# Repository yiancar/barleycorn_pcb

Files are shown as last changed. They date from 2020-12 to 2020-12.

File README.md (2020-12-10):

Barleycorn
================

barleycorn

This ANSI/ISO 1800 F-row less keyboard kit is made using ONLY through hole components and inspired by the [Plaid](https://github.com/hsgw/plaid).

Atmega328p with VUSB on [QMK firmware](https://github.com/qmk/qmk_firmware).

To alter the pcb use KiCAD V5.0 or newer as it already contains most of the libraries. The additional libraries are provided.

License
===========

This project is licensed under the [Creative Commons Attribution-NonCommercial 4.0 International License](https://creativecommons.org/licenses/by-nc/4.0/).

If you have remixed, adapted or build upon this work and wish to remove the non-commercial clause for your own project please contact me at https://www.yiancar-designs.com. Your request is more than likely to be granted. The non-commercial part of the license is intended to avoid direct copies of the work to be sold for commercial gain by third parties.

The USB4085-GF-A footprint, symbol and 3D model are licensed under [Attribution-ShareAlike 4.0 International](https://creativecommons.org/licenses/by-sa/4.0/). Originally created by [SnapEDA](https://snapeda.com). The footprint has been modified to increase the hole size of the shield pads.



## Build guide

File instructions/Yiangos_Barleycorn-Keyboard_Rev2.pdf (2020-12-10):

# Assembly Instructions

# Barleycorn Keyboard

# Welcome to your new

Barleycorn Keyboard.

Before we start, make sure you have the following:

- Soldering Iron
- Solder
- Cutters
- Stabilizers
- Mechanical Switches (preferably PCB mount)
- Keycaps
- USB C cable

This kit is designed with only through-hole components.

Component Identification

4.7uF Electrolytic
Capacitor

75Ohm Resistors
Colours: Purple,
Green, Black Gold,
Brown

22pF Ceramic
Capacitors
Markings: 22

10k Ohm Resistor
Colours: Brown, Black,
Black, Red, Brown

100nF Ceramic
Capacitors
Markings: 104

1.5k Ohm Resistors
Colours: Brown, Green,
Black, Brown, Brown

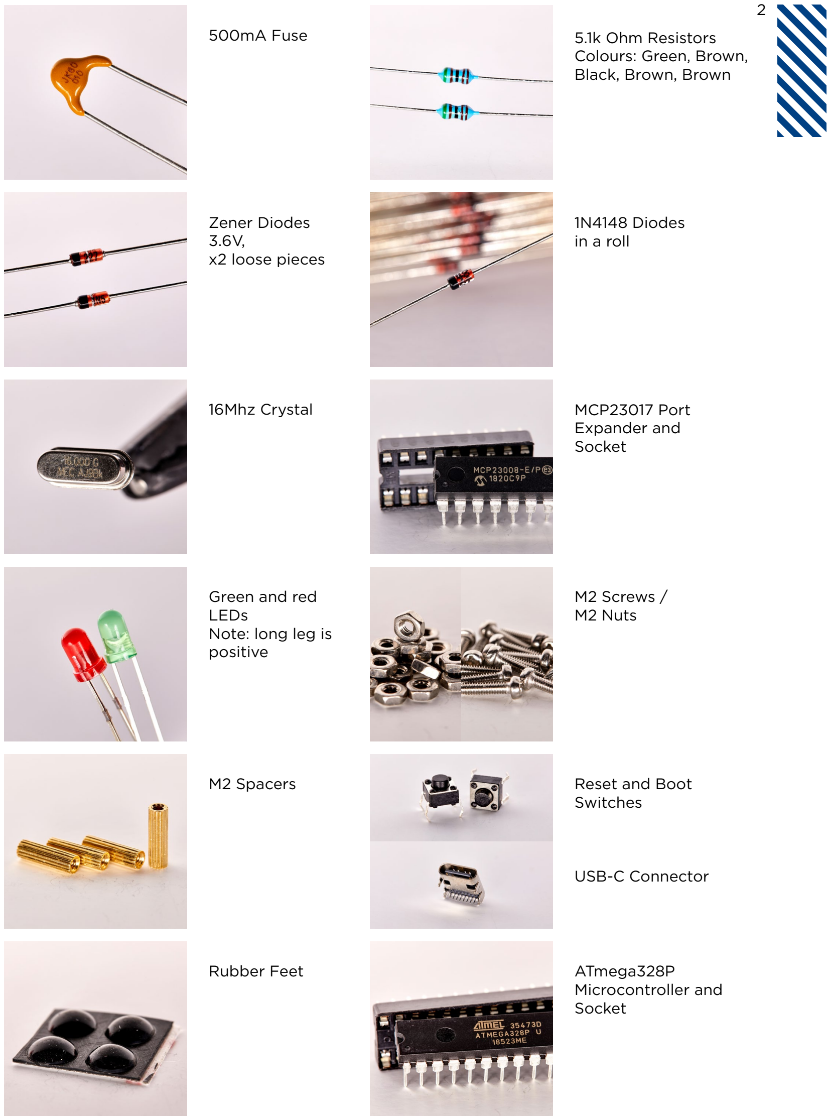
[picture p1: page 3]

500mA Fuse

1N4148 Diodes
in a roll

Zener Diodes
3.6V,
x2 loose pieces

MCP23017 Port
Expander and
Socket

16Mhz Crystal

M2 Screws /
M2 Nuts

Green and red
LEDs
Note: long leg is
positive

Reset and Boot
Switches

USB-C Connector

M2 Spacers

Rubber Feet | ATmega328P Microcontroller and Socket

5.1k Ohm Resistors
Colours: Green, Brown,
Black, Brown, Brown

# Assembly Instructions

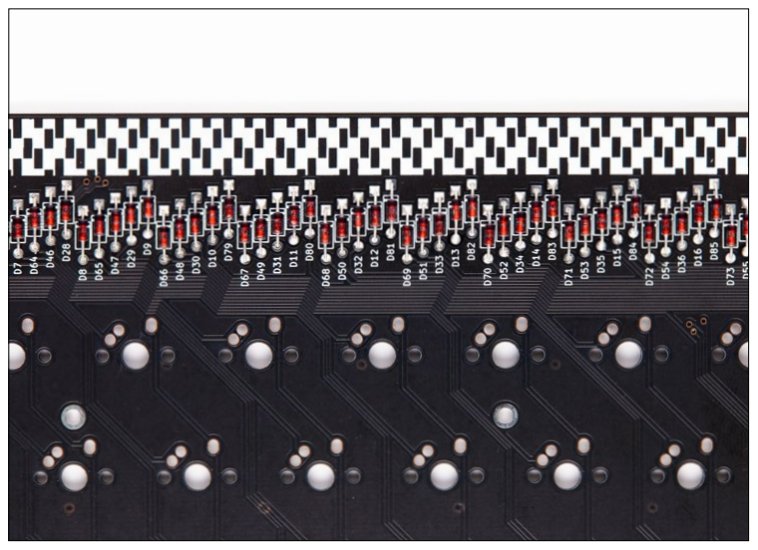
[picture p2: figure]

Step 1

Solder 1N4148 Diodes under the graphic as shown in the picture. The black line from the diodes goes to the top.

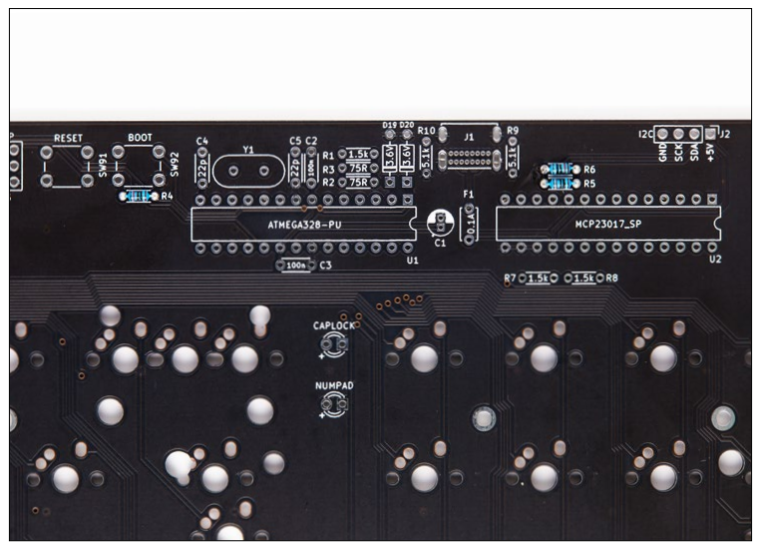
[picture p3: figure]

Step 2

Solder the x3 10k Ohm resistors; R4, R5, and R6. Those components have no specific orientation.

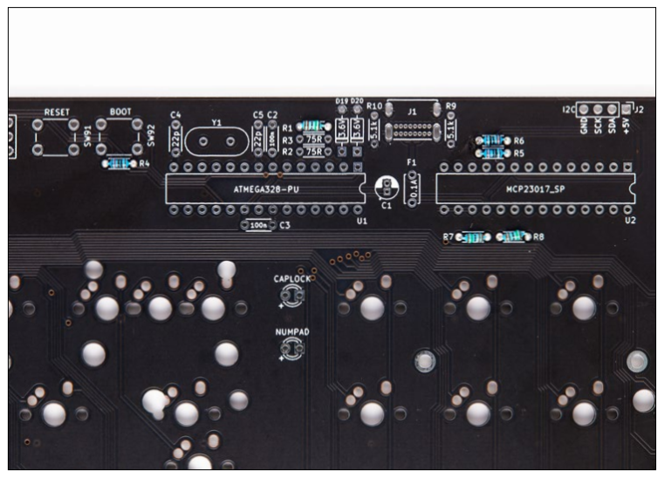
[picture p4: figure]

Step 3

Solder the x3 1.5k Ohm resistors; R1, R7, and R8. Those components have no specific orientation.

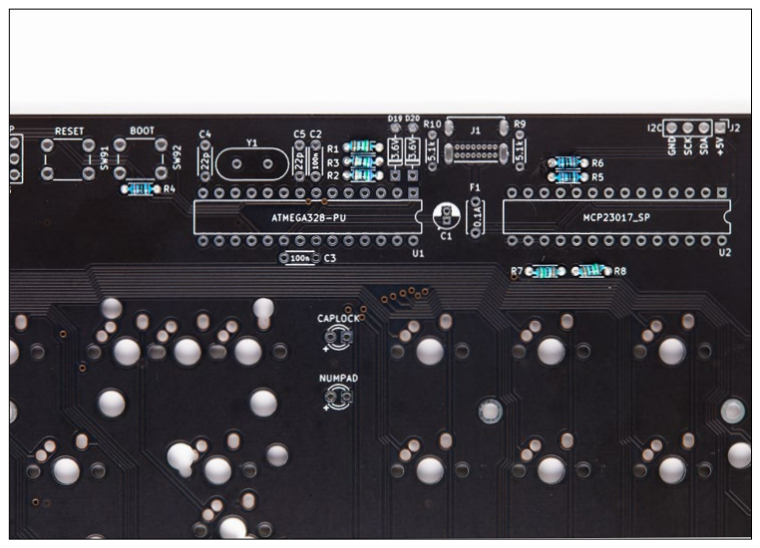
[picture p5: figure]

Step 4

Solder the x2 75 Ohm resistors; R2 and R3. Those components have no specific orientation.

# Assembly Instructions

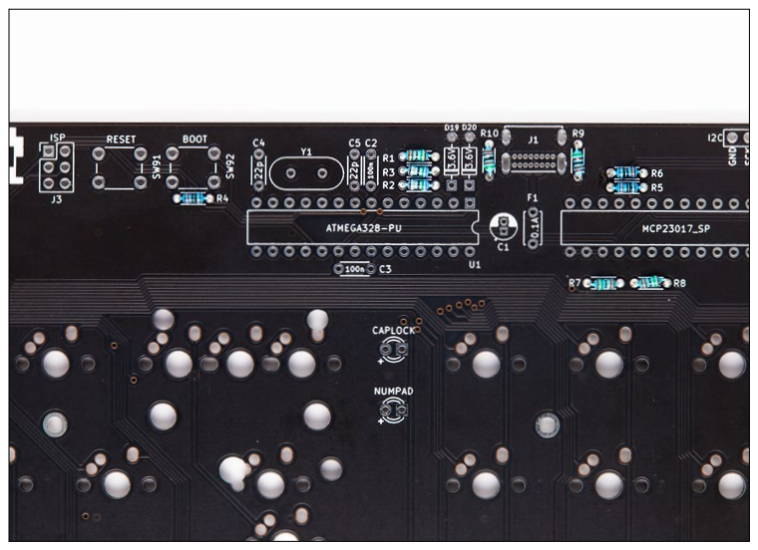
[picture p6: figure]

Step 5

Solder the x2 5.1k Ohm resistors; R9 and R10. These components have no specific orientation.

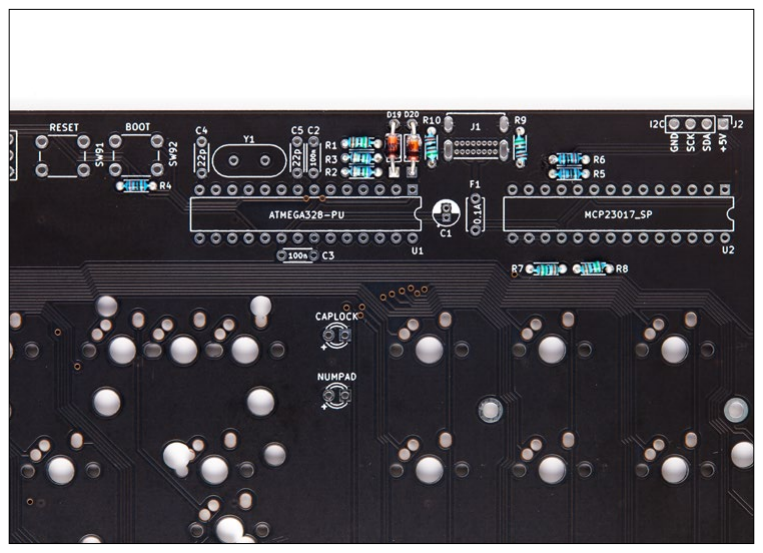
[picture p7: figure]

Step 6

Solder the x2 Zener diodes; D19 and D20. The black line is at the bottom.

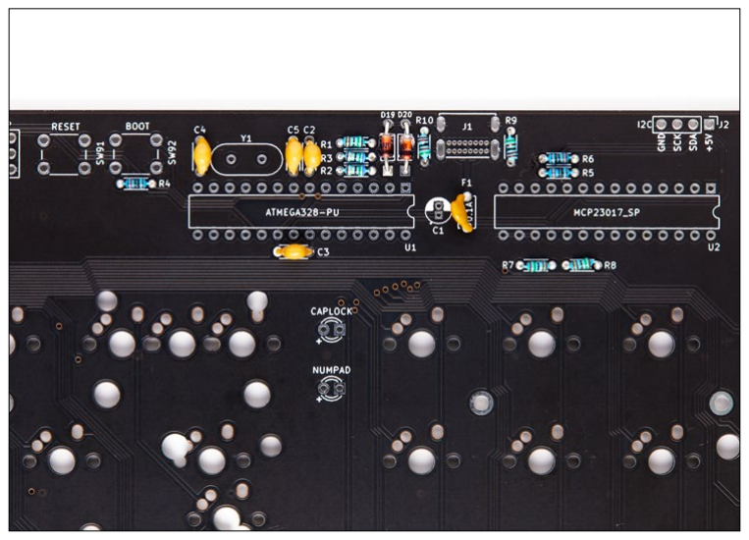
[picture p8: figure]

Step 7

Solder the x2 22pF capacitors; C4 and C5.

Note: Do not over-pull the legs through the PCB. These capacitors are very fragile and can crack. These components have no specific orientation.

Solder the x2 100nF capacitors; C2 and C3. These components have no specific orientation.

Solder the fuse, F1. This component has no specific orientation.

# Assembly Instructions

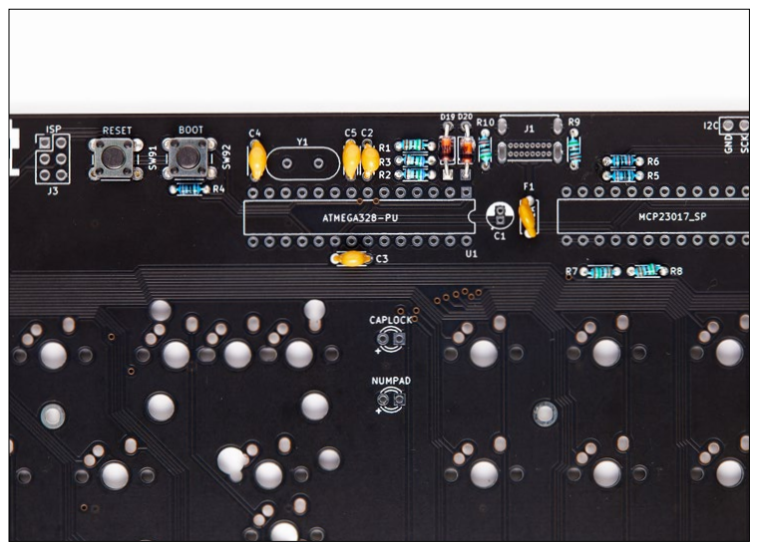
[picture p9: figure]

Step 8

Solder the x2 switches; SW91 and SW92. These components have no specific orientation.

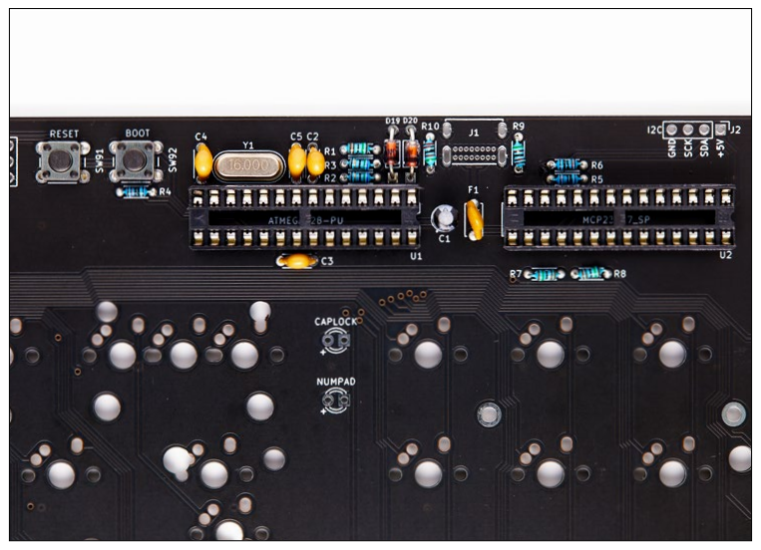
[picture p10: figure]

Step 9

Solder the electrolytic capacitor, C1. Negative (-) goes at the top. Solder the crystal at Y1, this component does not have any specific orientation.

Solder the x2 chip sockets. The small one goes to the U2 and the big one goes to U1, as in the picture.

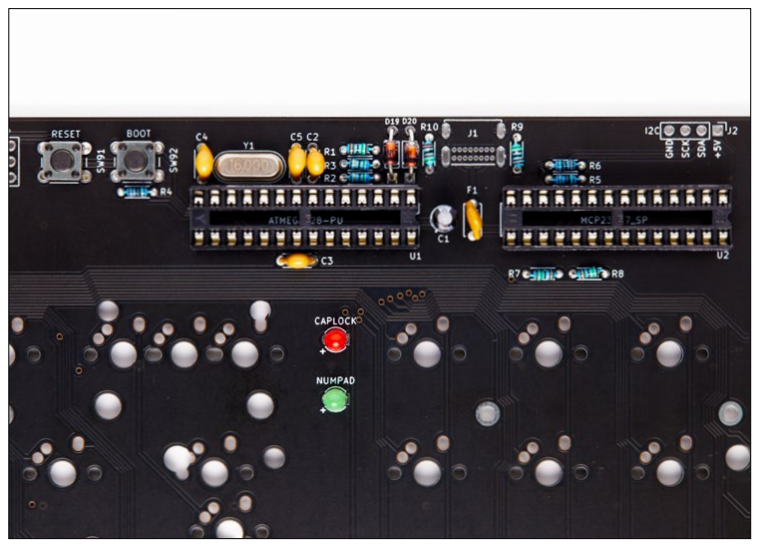
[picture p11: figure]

Step 10

Solder the LEDs as shown in the picture. The long leg is the positive.

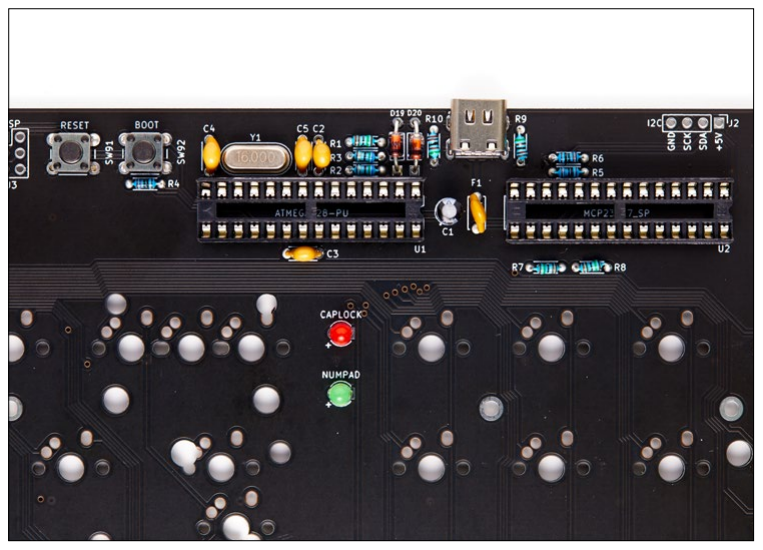
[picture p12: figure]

Step 11

Solder the USB socket. The small pins might not come through the PCB but still add plenty of solder and flux. Solder the shield pins last.

# Assembly Instructions

Step 12

Put the x2 chips in their sockets. The MCU is pre-programmed with the default ANSI keymap. Re-programming instructions are on page 9. The U1 chip’s semi-circle mark goes to the right. The U2 semi-circle mark goes to the right. Bend the legs of the chips inwards to fit in the sockets!

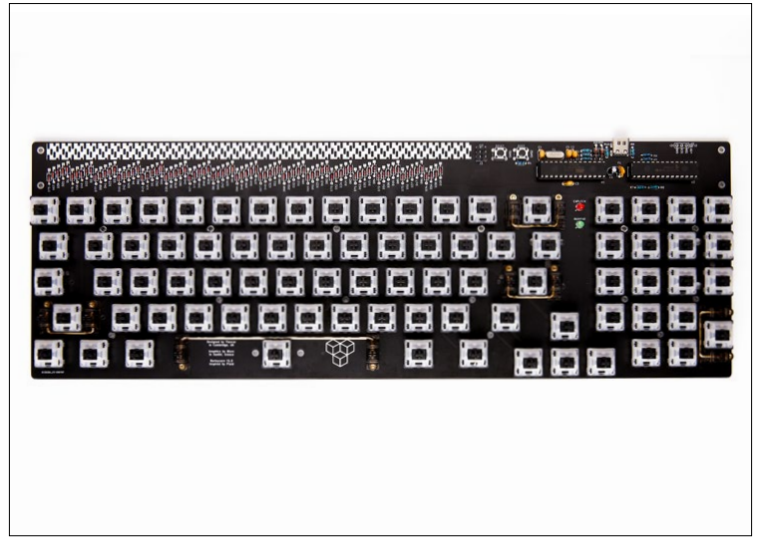
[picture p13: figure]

Step 13

Solder all the switches according to your desired layout. Add the stabilizers.

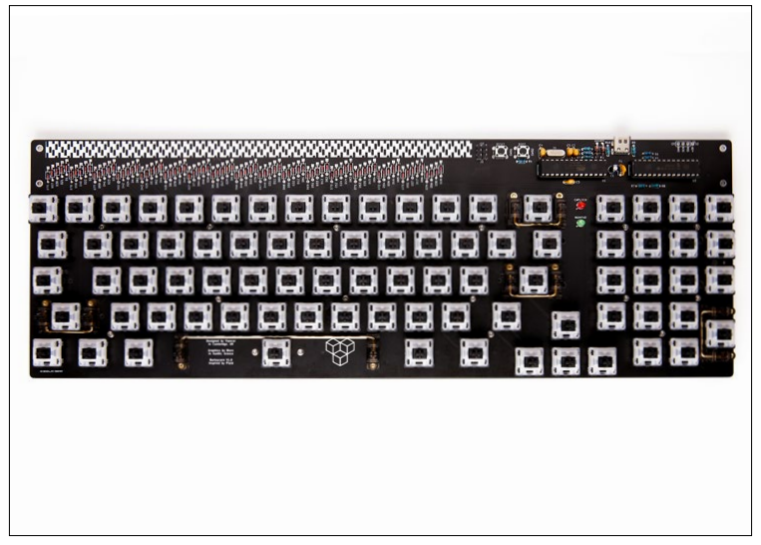
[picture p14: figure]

Step 14

Screw the x16 M2 screws as shown in the picture. Don’t add screws at the 4 top holes for the plexyglass. The screws are inserted from the top of the PCB.

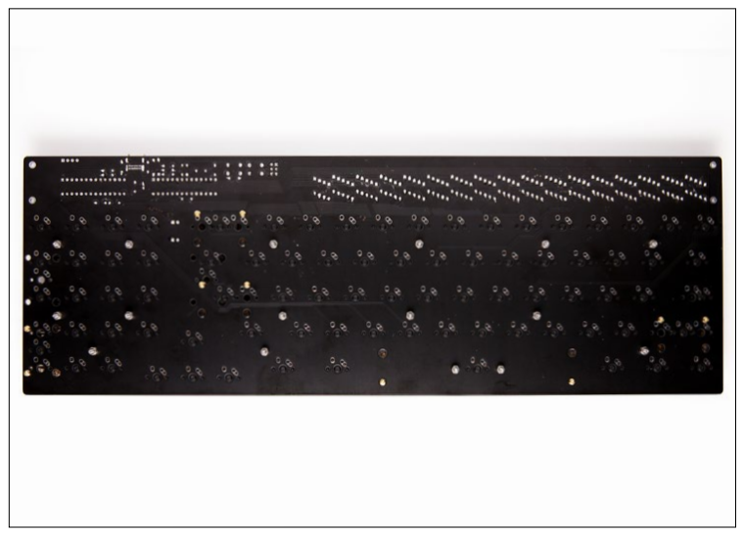
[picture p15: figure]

Step 15

Screw x2 M2 nuts on each of the 16 screws from the bottom.

# Assembly Instructions

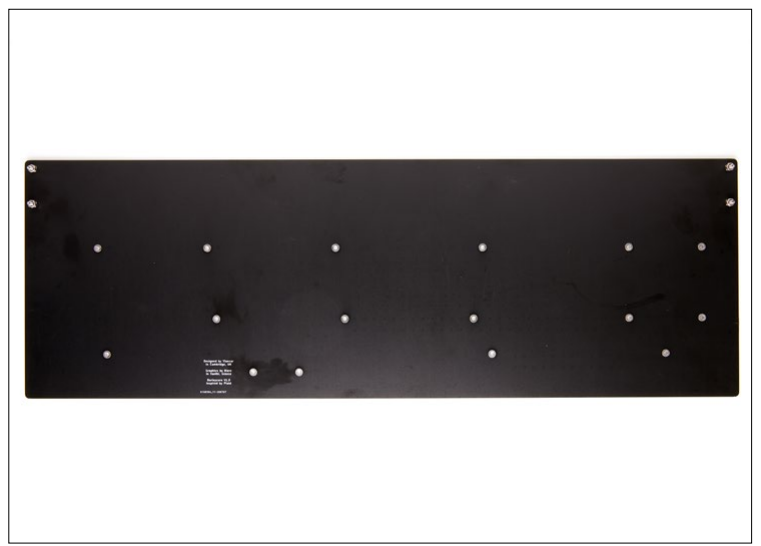
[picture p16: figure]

Step 16

Put the x4 M2 screws from the bottom of the bottom PCB. These screws are for the plexiglass.

Add x2 M2 nuts for each screw from the top of the bottom PCB.

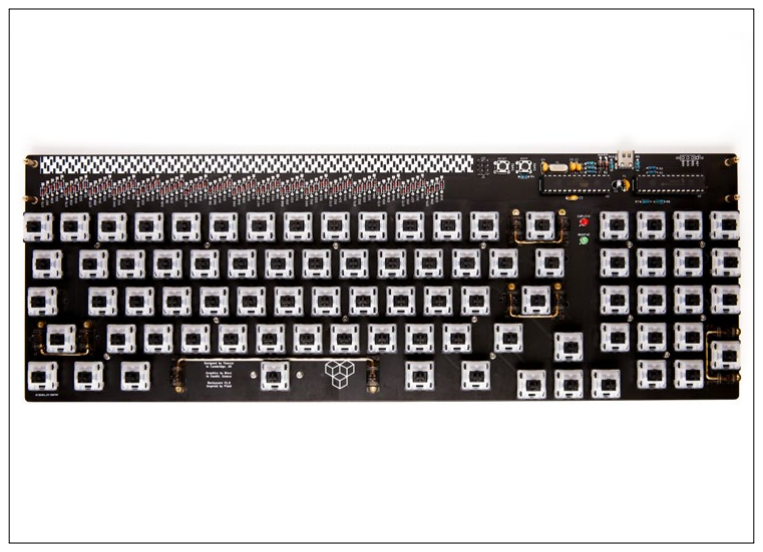
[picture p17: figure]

Step 17

Insert the bottom PCB and the top PCB together. Secure the x4 plexiglass screws with the x4 spacers.

Step 18

Place the plexiglass on top of the spacers and secure it with x4 M2 screws.

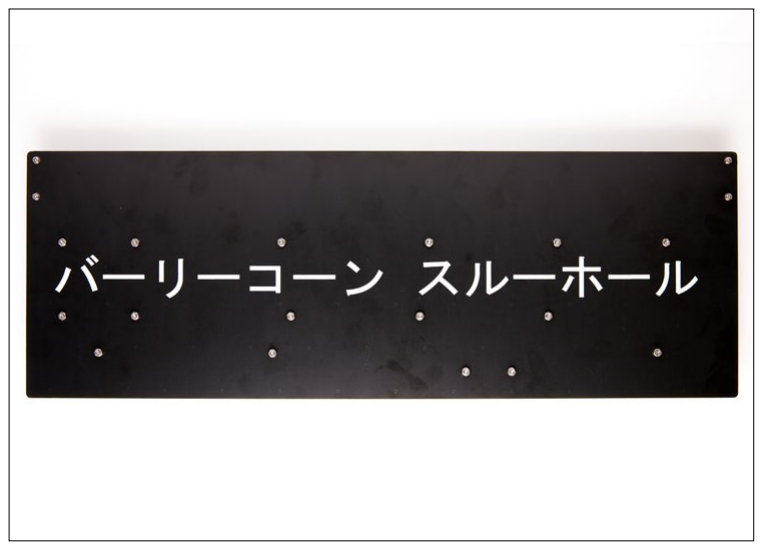
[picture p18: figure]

Step 19

Turn the keyboard upside down and secure the bottom PCB with the last x16 M2 nuts.

# Assembly Instructions

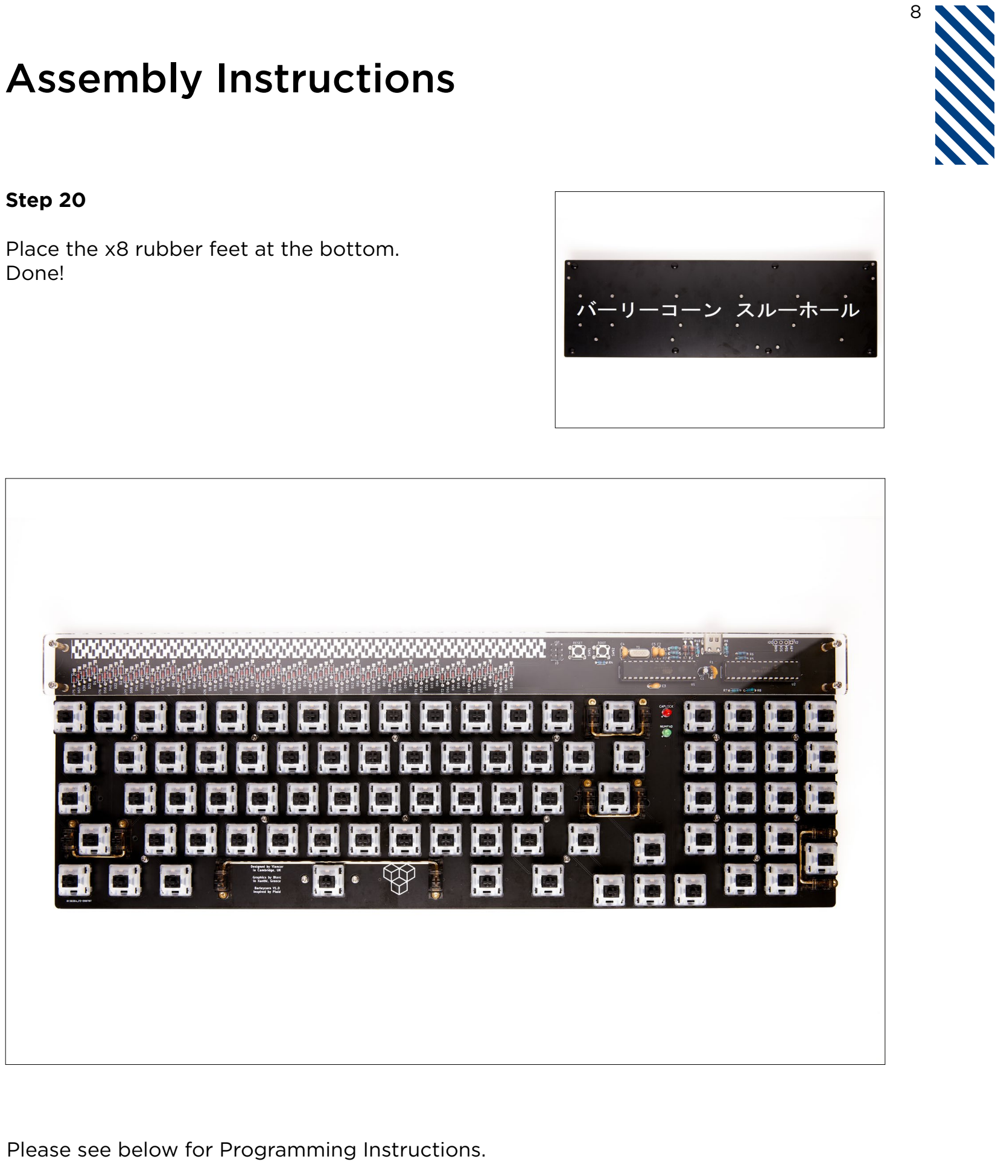
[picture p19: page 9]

Step 20

Place the x8 rubber feet at the bottom. Done!

Please see below for Programming Instructions.

# Programming Instructions Using VIA

Currently, media and mouse keycodes cannot be used using VIA.

The keyboard is shipped with VIA enabled. If you have programmed using QMK configurator and want to go back to VIA please flash the VIA keymap from our website.

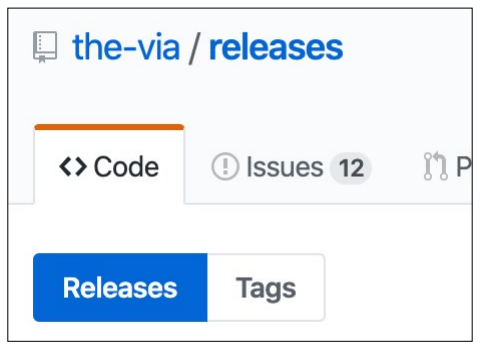
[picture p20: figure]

Step 1

Download VIA from:

https://github.com/the-via/releases/releases/latest (https://github.com/the-via/releases/releases/latest)

Step 2

With the keyboard connected, open VIA.

Step 3

To change the keymap, press on the desired key and then select the new keycode from below. The change is instantaneous.

To change layouts, use the layout tab.

# Programming Instructions Using QMK

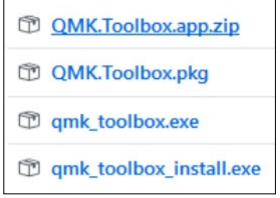
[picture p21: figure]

Step 1

Download the latest QMK Toolbox from:

https://github.com/qmk/qmk_toolbox/releases (http://github.com/qmk/qmk_toolbox/releases)

If you are using Windows download the “.exe”. If you are using MacOS download the “.pkg”.

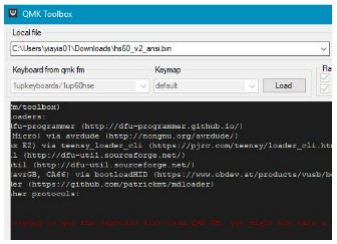
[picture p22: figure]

Step 2

Install the downloaded package.

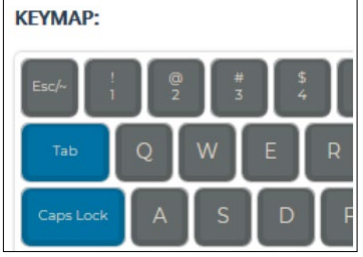
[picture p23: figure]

Step 3

Create your desired keymap from:

https://config.qmk.fm/#/barleycorn/LAYOUT_all (https://config.qmk.fm/#/barleycorn/LAYOUT_all)

Select the desired layout first.

Step 4

Press Compile button. Make sure the compilation has completed successfully.

# Programming Instructions Using QMK

Step 5

Press FIRMWARE button to download the “.hex”.

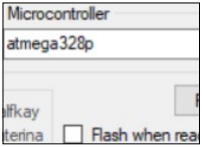
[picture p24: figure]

Step 6

In QMK toolbox press Open and select the downloaded “.hex”. Select atmega328p from the microcontroller menu.

Step 7

Press and hold the BOOT button. Press and release the RESET button. Release the BOOT button, QMK toolbox should detect USBasp.

Step 8

Press the Flash button in QMK toolbox. Once you see the Success message, press the RESET button.

Done! Enjoy your new keymap!

## yiancar-designs.com hello@yiancar-designs.com (http://yiancar-designs.com/contact-us/)

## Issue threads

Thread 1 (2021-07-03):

Missing Step in instructions

FlamingChickenG, 2021-07-03:
Missing step to solder on the 16Mhz Crystal to the board between steps 8 and 9.

yiancar, 2021-07-03:
Hello,
it says it at the text of step 9:
https://raw.githubusercontent.com/yiancar/barleycorn_pcb/main/instructions/Yiangos_Barleycorn-Keyboard_Rev2.pdf

Closed 2021-07-05.

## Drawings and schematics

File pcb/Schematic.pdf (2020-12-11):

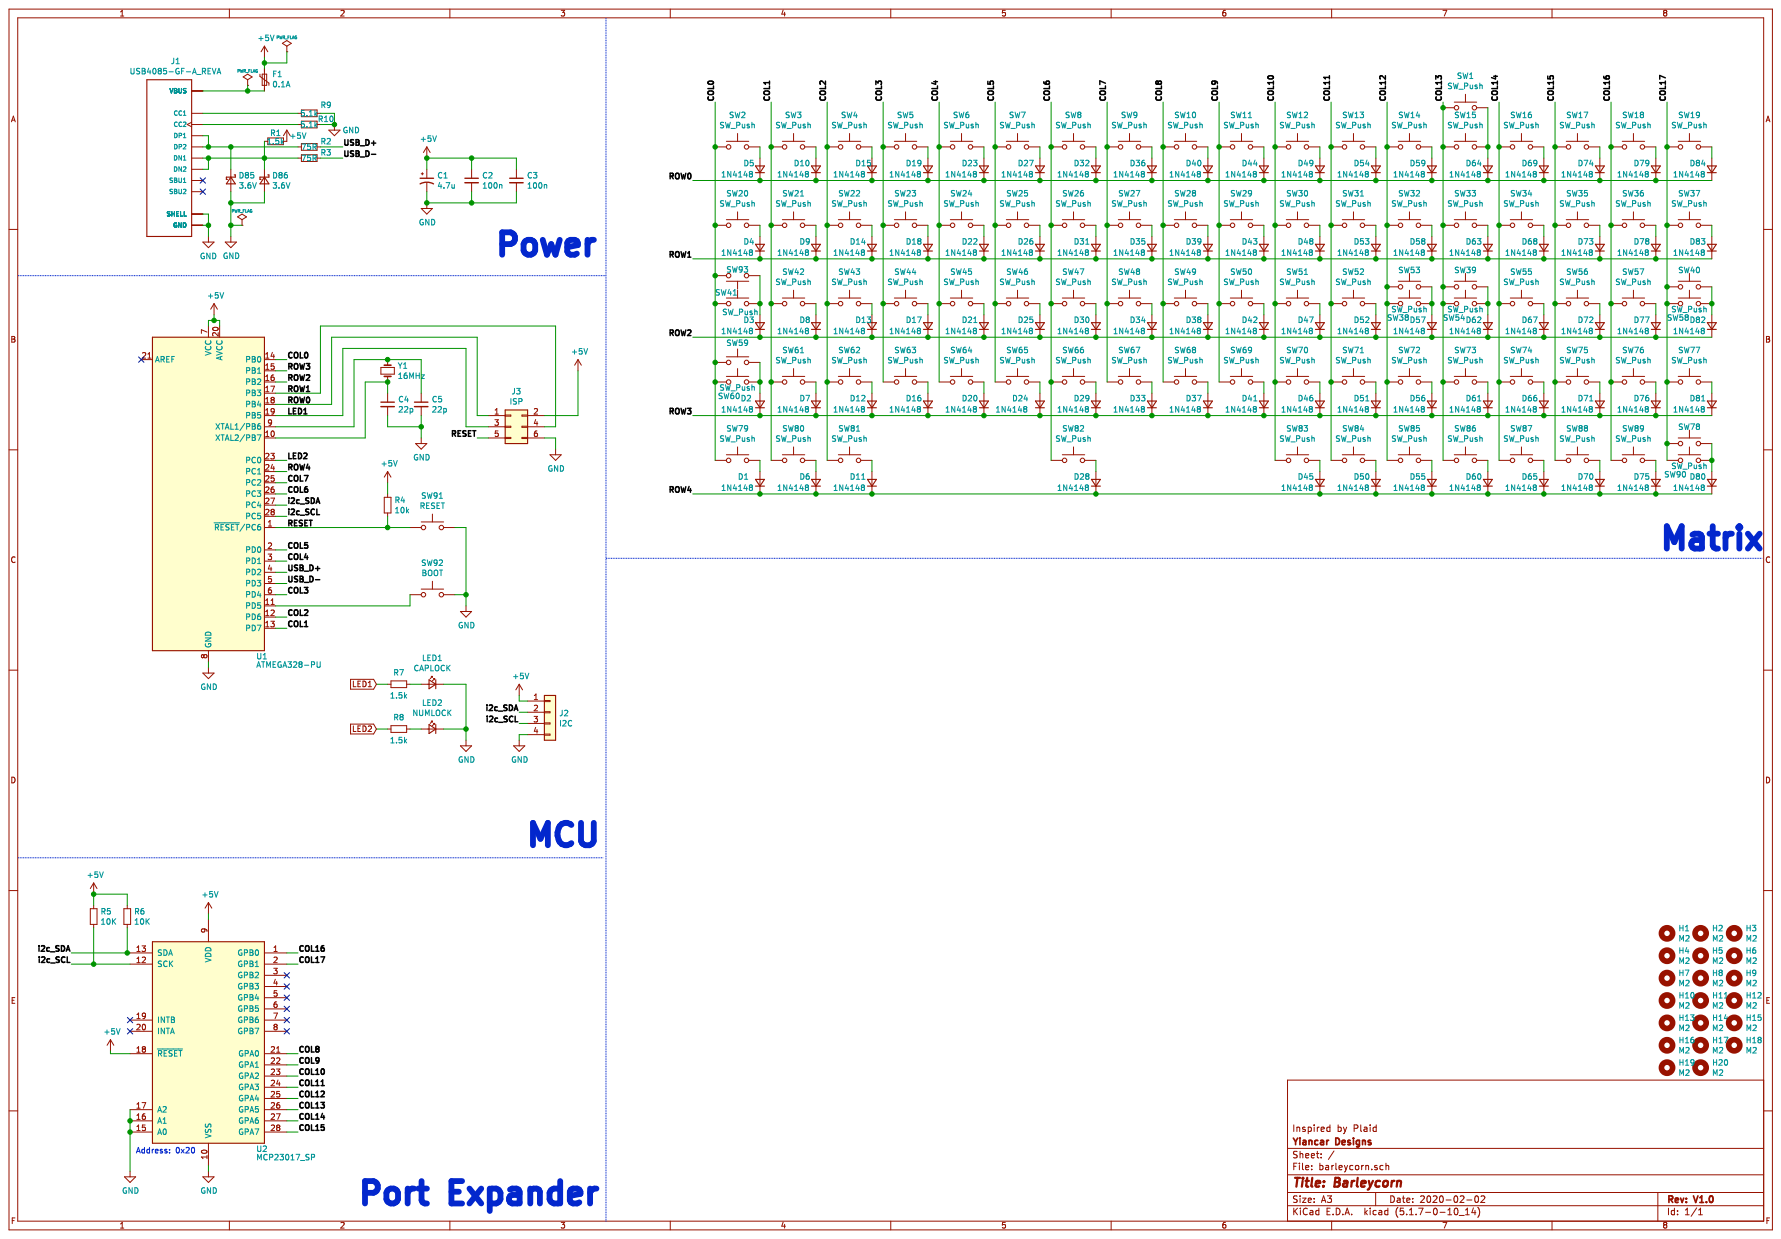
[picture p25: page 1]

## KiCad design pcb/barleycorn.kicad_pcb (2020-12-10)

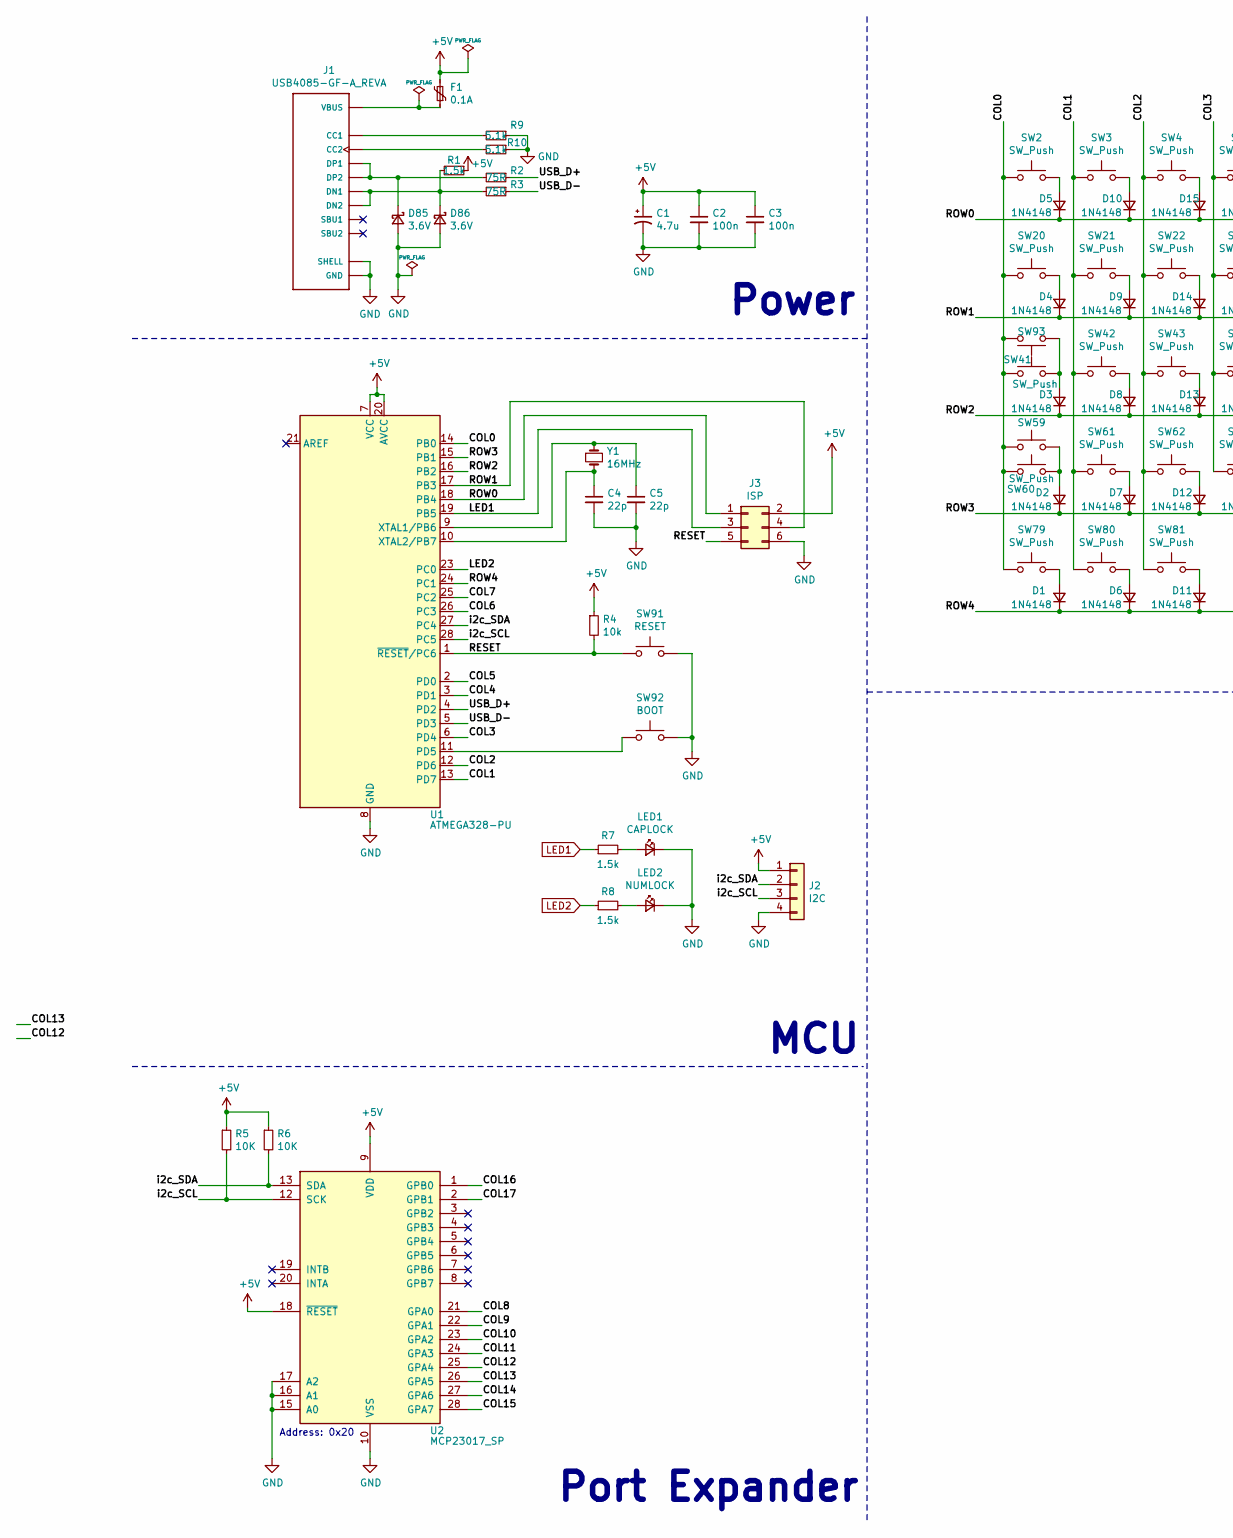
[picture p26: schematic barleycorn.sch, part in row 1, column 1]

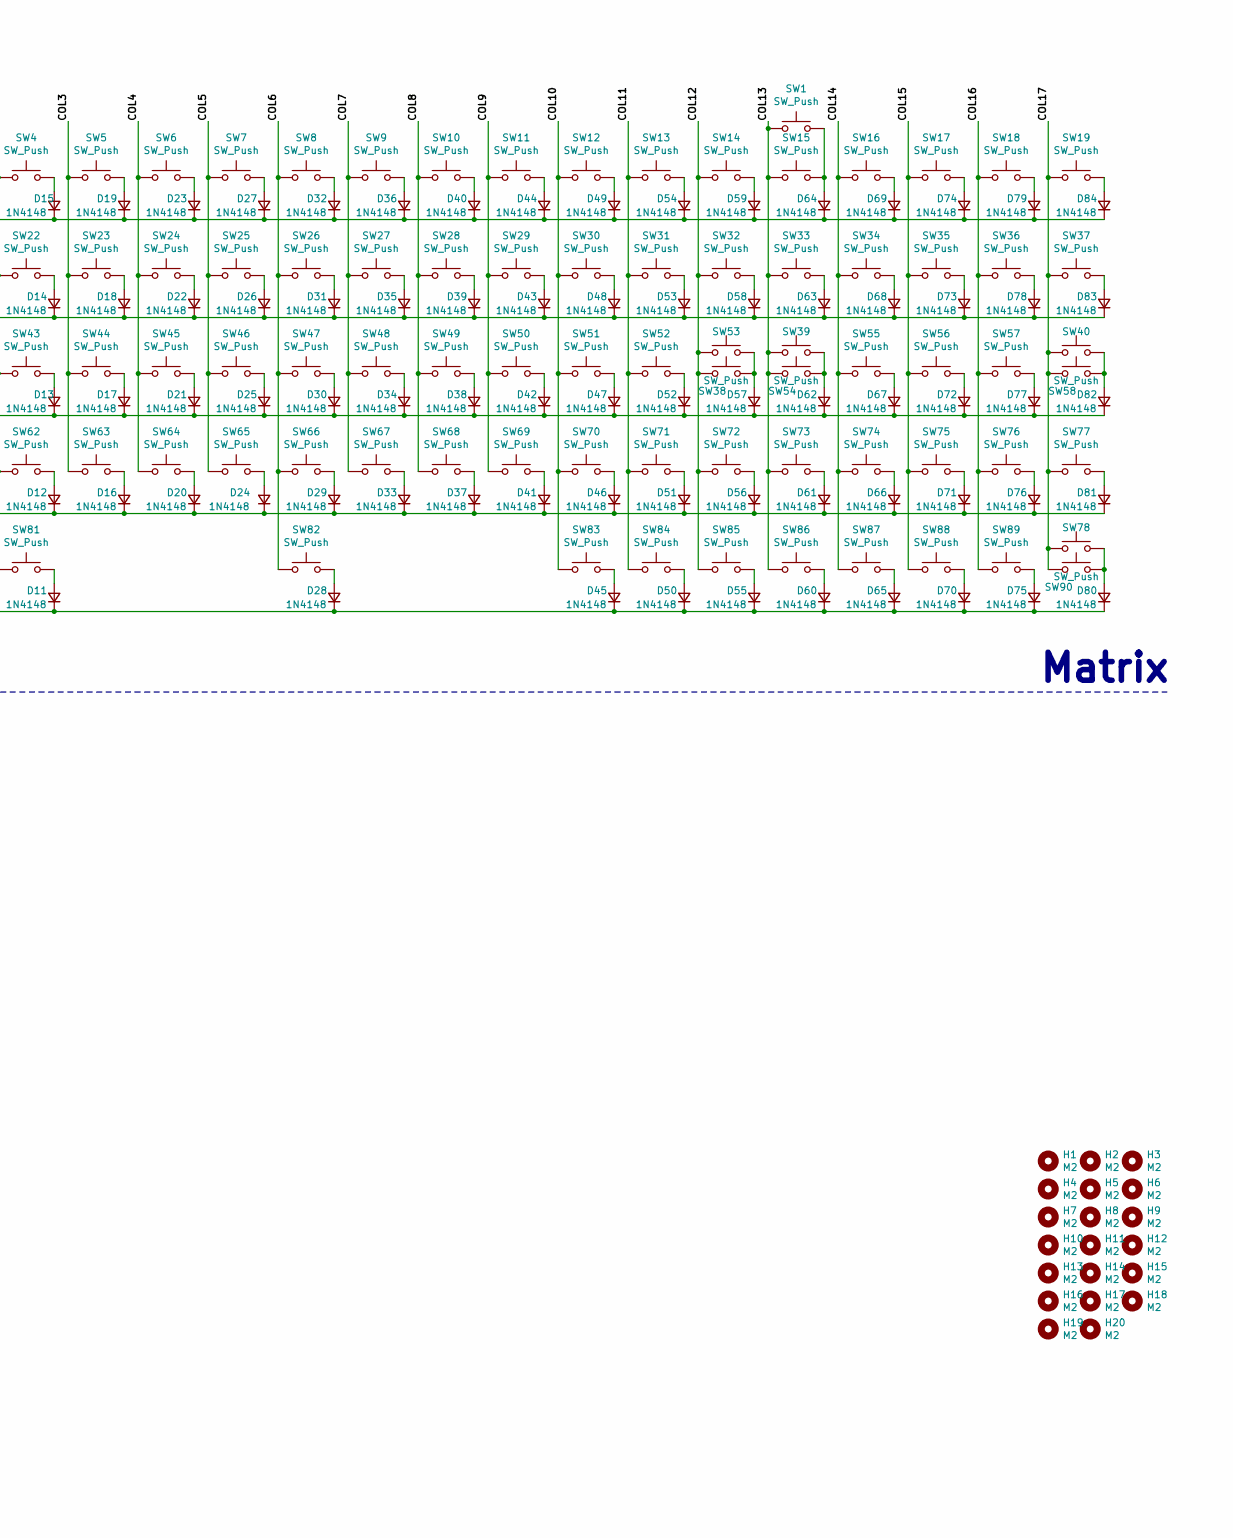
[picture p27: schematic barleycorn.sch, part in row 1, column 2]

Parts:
C1: 4.7u; CP_Radial_D4.0mm_P1.50mm
C2, C3: 100n; C_Disc_D4.3mm_W1.9mm_P5.00mm
C4, C5: 22p; C_Disc_D4.3mm_W1.9mm_P5.00mm
D1, D2, D3, D4, D5, D6, D7, D8, D9, D10, D11, D12, D13, D14, D15, D16, D17, D18, D19, D20, D21, D22, D23, D24, D25, D26, D27, D28, D29, D30, D31, D32, D33, D34, D35, D36, D37, D38, D39, D40, D41, D42, D43, D44, D45, D46, D47, D48, D49, D50, D51, D52, D53, D54, D55, D56, D57, D58, D59, D60, D61, D62, D63, D64, D65, D66, D67, D68, D69, D70, D71, D72, D73, D74, D75, D76, D77, D78, D79, D80, D81, D82, D83, D84: 1N4148; D_DO-35_SOD27_P7.62mm_Horizontal
D85, D86: 3.6V; D_DO-35_SOD27_P7.62mm_Horizontal
F1: 0.1A; C_Disc_D5.0mm_W2.5mm_P5.00mm
H1, H2, H3, H4, H5, H6, H7, H8, H9, H10, H11, H12, H13, H14, H15, H16, H17, H18, H19, H20: M2; MountingHole_2.2mm_M2_DIN965_Pad
J1: USB4085-GF-A_REVA; GCT_USB4085-GF-A_REVA
J2: I2C; PinHeader_1x04_P2.54mm_Vertical
J3: ISP; PinHeader_2x03_P2.54mm_Vertical
LED1: CAPLOCK; LED_D3.0mm_Clear
LED2: NUMLOCK; LED_D3.0mm_Clear
R1, R7, R8: 1.5k; R_Axial_DIN0204_L3.6mm_D1.6mm_P5.08mm_Horizontal
R2, R3: 75R; R_Axial_DIN0204_L3.6mm_D1.6mm_P5.08mm_Horizontal
R4: 10k; R_Axial_DIN0204_L3.6mm_D1.6mm_P5.08mm_Horizontal
R5, R6: 10K; R_Axial_DIN0204_L3.6mm_D1.6mm_P5.08mm_Horizontal
R9, R10: 5.1k; R_Axial_DIN0204_L3.6mm_D1.6mm_P5.08mm_Horizontal
SW1, SW40, SW78: SW_Push; MX-2U-NoLED
SW2, SW3, SW4, SW5, SW6, SW7, SW8, SW9, SW10, SW11, SW12, SW13, SW14, SW15, SW16, SW17, SW18, SW19, SW21, SW22, SW23, SW24, SW25, SW26, SW27, SW28, SW29, SW30, SW31, SW32, SW33, SW34, SW35, SW36, SW37, SW38, SW42, SW43, SW44, SW45, SW46, SW47, SW48, SW49, SW50, SW51, SW52, SW55, SW56, SW57, SW58, SW61, SW62, SW63, SW64, SW65, SW66, SW67, SW68, SW69, SW70, SW71, SW73, SW74, SW75, SW76, SW77, SW85, SW86, SW87, SW88, SW89, SW90: SW_Push; MX-1U-NoLED
SW20, SW53, SW83, SW84: SW_Push; MX-1.5U-NoLED
SW39: SW_Push; MX-ISO-ReversedStabilizers
SW41, SW72: SW_Push; MX-1.75U-NoLED
SW54, SW60: SW_Push; MX-2.25U-NoLED
SW59, SW79, SW80, SW81, SW93: SW_Push; MX-1.25U-NoLED
SW82: SW_Push; MX-6.25U-ReversedStabilizers-NoLED
SW91: RESET; SW_PUSH_6mm
SW92: BOOT; SW_PUSH_6mm
U1: ATMEGA328-PU; DIP-28_W7.62mm
U2: MCP23017_SP; DIP-28_W7.62mm
Y1: 16MHz; Crystal_HC49-4H_Vertical

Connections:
+5V: C1.1, C2.1, C3.1, F1.2, J2.1, J3.2, R1.1, R4.1, R5.1, R6.1, U1.7 (VCC), U1.20 (AVCC), U2.9 (VDD), U2.18 (~RESET~)
/COL0: SW2.2, SW20.2, SW41.2, SW59.2, SW60.2, SW79.2, SW93.1, U1.14 (PB0)
/COL1: SW3.2, SW21.2, SW42.2, SW61.2, SW80.2, U1.13 (PD7)
/COL2: SW4.2, SW22.2, SW43.2, SW62.2, SW81.2, U1.12 (PD6)
/COL3: SW5.2, SW23.2, SW44.2, SW63.2, U1.6 (PD4)
/COL4: SW6.2, SW24.2, SW45.2, SW64.2, U1.3 (PD1)
/COL5: SW7.2, SW25.2, SW46.2, SW65.2, U1.2 (PD0)
/COL6: SW8.2, SW26.2, SW47.2, SW66.2, SW82.2, U1.26 (PC3)
/COL7: SW9.2, SW27.2, SW48.2, SW67.2, U1.25 (PC2)
/COL8: SW10.2, SW28.2, SW49.2, SW68.2, U2.21 (GPA0)
/COL9: SW11.2, SW29.2, SW50.2, SW69.2, U2.22 (GPA1)
/COL10: SW12.2, SW30.2, SW51.2, SW70.2, SW83.2, U2.23 (GPA2)
/COL11: SW13.2, SW31.2, SW52.2, SW71.2, SW84.2, U2.24 (GPA3)
/COL12: SW14.2, SW32.2, SW38.2, SW53.2, SW72.2, SW85.2, U2.25 (GPA4)
/COL13: SW1.2, SW15.2, SW33.2, SW39.2, SW54.2, SW73.2, SW86.2, U2.26 (GPA5)
/COL14: SW16.2, SW34.2, SW55.2, SW74.2, SW87.2, U2.27 (GPA6)
/COL15: SW17.2, SW35.2, SW56.2, SW75.2, SW88.2, U2.28 (GPA7)
/COL16: SW18.2, SW36.2, SW57.2, SW76.2, SW89.2, U2.1 (GPB0)
/COL17: SW19.2, SW37.2, SW40.2, SW58.2, SW77.2, SW78.2, SW90.2, U2.2 (GPB1)
/RESET: J3.5, R4.2, SW91.1, U1.1 (~RESET~/PC6)
/ROW0: D5.1 (K), D10.1 (K), D15.1 (K), D19.1 (K), D23.1 (K), D27.1 (K), D32.1 (K), D36.1 (K), D40.1 (K), D44.1 (K), D49.1 (K), D54.1 (K), D59.1 (K), D64.1 (K), D69.1 (K), D74.1 (K), D79.1 (K), D84.1 (K), J3.1, U1.18 (PB4)
/ROW1: D4.1 (K), D9.1 (K), D14.1 (K), D18.1 (K), D22.1 (K), D26.1 (K), D31.1 (K), D35.1 (K), D39.1 (K), D43.1 (K), D48.1 (K), D53.1 (K), D58.1 (K), D63.1 (K), D68.1 (K), D73.1 (K), D78.1 (K), D83.1 (K), J3.4, U1.17 (PB3)
/ROW2: D3.1 (K), D8.1 (K), D13.1 (K), D17.1 (K), D21.1 (K), D25.1 (K), D30.1 (K), D34.1 (K), D38.1 (K), D42.1 (K), D47.1 (K), D52.1 (K), D57.1 (K), D62.1 (K), D67.1 (K), D72.1 (K), D77.1 (K), D82.1 (K), U1.16 (PB2)
/ROW3: D2.1 (K), D7.1 (K), D12.1 (K), D16.1 (K), D20.1 (K), D24.1 (K), D29.1 (K), D33.1 (K), D37.1 (K), D41.1 (K), D46.1 (K), D51.1 (K), D56.1 (K), D61.1 (K), D66.1 (K), D71.1 (K), D76.1 (K), D81.1 (K), U1.15 (PB1)
/ROW4: D1.1 (K), D6.1 (K), D11.1 (K), D28.1 (K), D45.1 (K), D50.1 (K), D55.1 (K), D60.1 (K), D65.1 (K), D70.1 (K), D75.1 (K), D80.1 (K), U1.24 (PC1)
/USB_D+: R2.1, U1.4 (PD2)
/USB_D-: R3.1, U1.5 (PD3)
/i2c_SCL: J2.3, R5.2, U1.28 (PC5), U2.12 (SCK)
/i2c_SDA: J2.2, R6.2, U1.27 (PC4), U2.13 (SDA)
GND: C1.2, C2.2, C3.2, C4.2, C5.2, D85.2 (A), D86.2 (A), J1.A1 (GND), J1.A12 (GND), J1.B1 (GND), J1.B12 (GND), J1.P1 (SHELL), J1.P2 (SHELL), J1.P3 (SHELL), J1.P4 (SHELL), J2.4, J3.6, LED1.1 (K), LED2.1 (K), R9.1, R10.1, SW91.2, SW92.2, U1.8 (GND), U1.22 (GND), U2.10 (VSS), U2.15 (A0), U2.16 (A1), U2.17 (A2)
LED1: J3.3, R7.1, U1.19 (PB5)
LED2: R8.1, U1.23 (PC0)
unnamed: C4.1, U1.10 (XTAL2/PB7), Y1.2
unnamed: C5.1, U1.9 (XTAL1/PB6), Y1.1
unnamed: D1.2 (A), SW79.1
unnamed: D2.2 (A), SW59.1, SW60.1
unnamed: D3.2 (A), SW41.1, SW93.2
unnamed: D4.2 (A), SW20.1
unnamed: D5.2 (A), SW2.1
unnamed: D6.2 (A), SW80.1
unnamed: D7.2 (A), SW61.1
unnamed: D8.2 (A), SW42.1
unnamed: D9.2 (A), SW21.1
unnamed: D10.2 (A), SW3.1
unnamed: D11.2 (A), SW81.1
unnamed: D12.2 (A), SW62.1
unnamed: D13.2 (A), SW43.1
unnamed: D14.2 (A), SW22.1
unnamed: D15.2 (A), SW4.1
unnamed: D16.2 (A), SW63.1
unnamed: D17.2 (A), SW44.1
unnamed: D18.2 (A), SW23.1
unnamed: D19.2 (A), SW5.1
unnamed: D20.2 (A), SW64.1
unnamed: D21.2 (A), SW45.1
unnamed: D22.2 (A), SW24.1
unnamed: D23.2 (A), SW6.1
unnamed: D24.2 (A), SW65.1
unnamed: D25.2 (A), SW46.1
unnamed: D26.2 (A), SW25.1
unnamed: D27.2 (A), SW7.1
unnamed: D28.2 (A), SW82.1
unnamed: D29.2 (A), SW66.1
unnamed: D30.2 (A), SW47.1
unnamed: D31.2 (A), SW26.1
unnamed: D32.2 (A), SW8.1
unnamed: D33.2 (A), SW67.1
unnamed: D34.2 (A), SW48.1
unnamed: D35.2 (A), SW27.1
unnamed: D36.2 (A), SW9.1
unnamed: D37.2 (A), SW68.1
unnamed: D38.2 (A), SW49.1
unnamed: D39.2 (A), SW28.1
unnamed: D40.2 (A), SW10.1
unnamed: D41.2 (A), SW69.1
unnamed: D42.2 (A), SW50.1
unnamed: D43.2 (A), SW29.1
unnamed: D44.2 (A), SW11.1
unnamed: D45.2 (A), SW83.1
unnamed: D46.2 (A), SW70.1
unnamed: D47.2 (A), SW51.1
unnamed: D48.2 (A), SW30.1
unnamed: D49.2 (A), SW12.1
unnamed: D50.2 (A), SW84.1
unnamed: D51.2 (A), SW71.1
unnamed: D52.2 (A), SW52.1
unnamed: D53.2 (A), SW31.1
unnamed: D54.2 (A), SW13.1
unnamed: D55.2 (A), SW85.1
unnamed: D56.2 (A), SW72.1
unnamed: D57.2 (A), SW38.1, SW53.1
unnamed: D58.2 (A), SW32.1
unnamed: D59.2 (A), SW14.1
unnamed: D60.2 (A), SW86.1
unnamed: D61.2 (A), SW73.1
unnamed: D62.2 (A), SW39.1, SW54.1
unnamed: D63.2 (A), SW33.1
unnamed: D64.2 (A), SW1.1, SW15.1
unnamed: D65.2 (A), SW87.1
unnamed: D66.2 (A), SW74.1
unnamed: D67.2 (A), SW55.1
unnamed: D68.2 (A), SW34.1
unnamed: D69.2 (A), SW16.1
unnamed: D70.2 (A), SW88.1
unnamed: D71.2 (A), SW75.1
unnamed: D72.2 (A), SW56.1
unnamed: D73.2 (A), SW35.1
unnamed: D74.2 (A), SW17.1
unnamed: D75.2 (A), SW89.1
unnamed: D76.2 (A), SW76.1
unnamed: D77.2 (A), SW57.1
unnamed: D78.2 (A), SW36.1
unnamed: D79.2 (A), SW18.1
unnamed: D80.2 (A), SW78.1, SW90.1
unnamed: D81.2 (A), SW77.1
unnamed: D82.2 (A), SW40.1, SW58.1
unnamed: D83.2 (A), SW37.1
unnamed: D84.2 (A), SW19.1
unnamed: D85.1 (K), J1.A6 (DP1), J1.B6 (DP2), R2.2
unnamed: D86.1 (K), J1.A7 (DN1), J1.B7 (DN2), R1.2, R3.2
unnamed: F1.1, J1.A4 (VBUS), J1.A9 (VBUS), J1.B4 (VBUS), J1.B9 (VBUS)
unnamed: J1.A5 (CC1), R9.2
unnamed: J1.B5 (CC2), R10.2
unnamed: LED1.2 (A), R7.2
unnamed: LED2.2 (A), R8.2
unnamed: SW92.1, U1.11 (PD5)

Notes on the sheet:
Power
Matrix
MCU
Port Expander
Address: 0x20

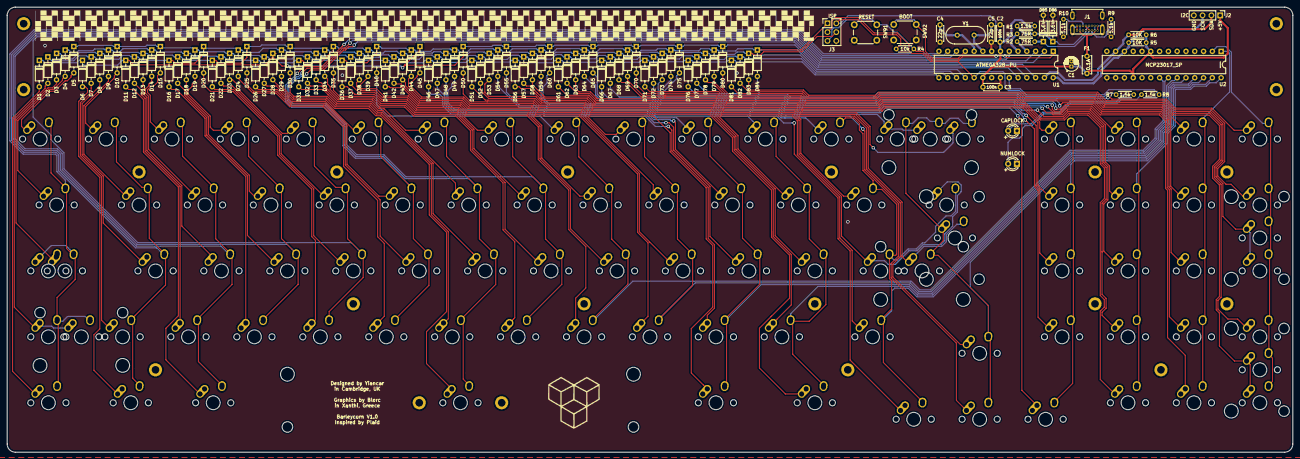
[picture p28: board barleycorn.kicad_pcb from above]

Board: 2 copper layers, 371.5 x 128.6 mm, 224 parts (0 on the bottom side), 126 nets.

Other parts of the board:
Ref**: Val**; barleycorn_logo

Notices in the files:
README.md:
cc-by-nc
